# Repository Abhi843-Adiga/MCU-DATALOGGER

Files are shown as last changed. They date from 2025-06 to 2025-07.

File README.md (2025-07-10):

MCU Data Logger (2-Layer & 4-Layer PCB Design) :        
-> A compact, modular microcontroller-based data logger designed using KiCad.         
-> This project includes both 2-layer and 4-layer PCB implementations managed through Git branching and git attributes.

Design Disclaimer :
These PCB designs are provided for educational purposes only.

Passed Checks:
The designs have successfully passed basic ERC (Electrical Rules Check) and DRC (Design Rule Check) in the KICAD.

Untested Aspects:
These designs have not been validated for advanced electrical performance.
Critical aspects that have not been analyzed or tested include:
->Signal Integrity (SI):High-speed signals (like SPI) have not been analyzed for reflections or timing issues.
->Power Integrity (PI):The power delivery network has not been simulated for stability.
->EMI/EMC:The design has not been tested for electromagnetic interference or compatibility. 

It will likely not pass regulatory certifications without further revisions.

Do not use these designs for a production-ready or commercial product without performing a thorough analysis and validation for SI, PI, and EMC.

Contributing:
If you have experience in SI/PI analysis, EMC hardening, or would like to improve the design, please feel free to fork the repository and submit a pull request.

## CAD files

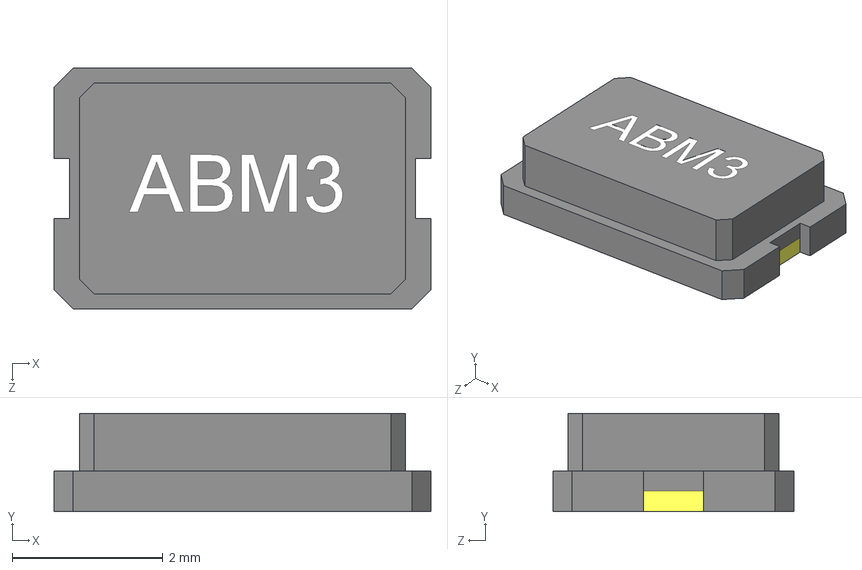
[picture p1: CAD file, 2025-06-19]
ABM3_16_000MHZ_B2_T/ABM3-16.000MHZ-B2-T.STEP
5.00 x 1.30 x 3.20 mm

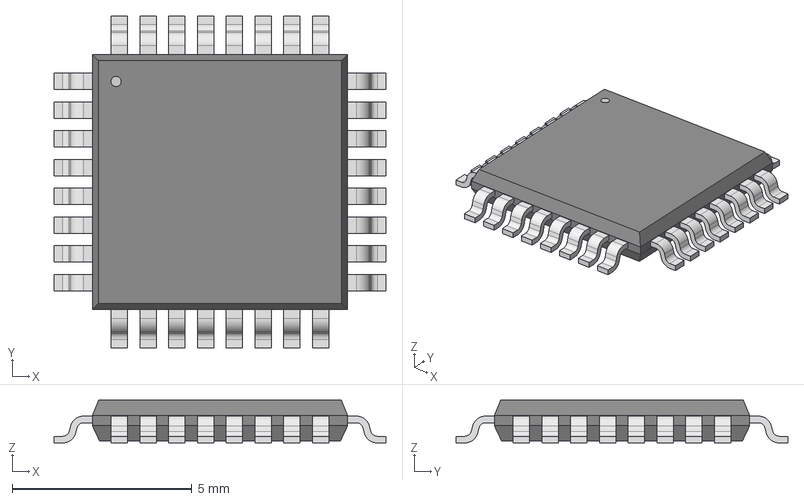
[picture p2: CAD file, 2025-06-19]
ATMEGA328P_AU (2)/TQFP32_32A_MCH.step
9.25 x 9.25 x 1.20 mm

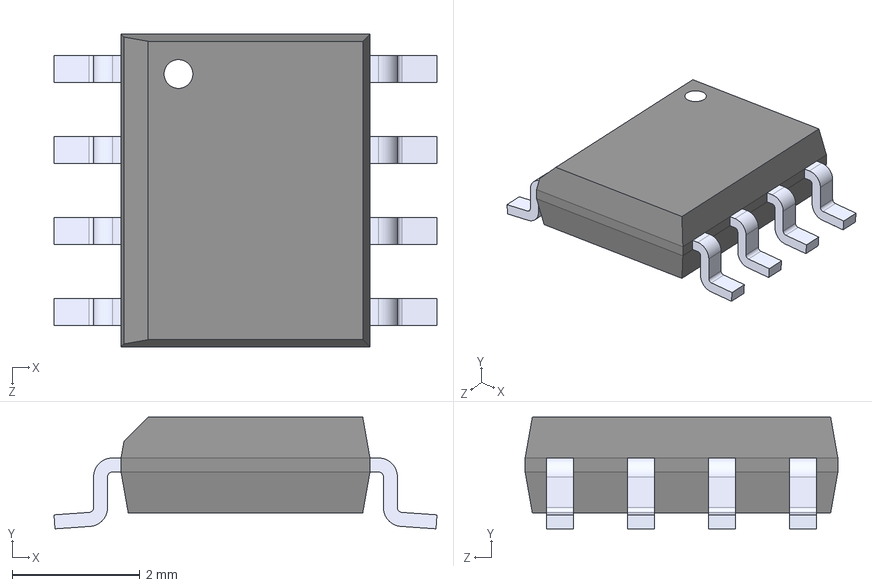
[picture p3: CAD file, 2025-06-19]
DS1337S (1)/DS1337S_.step
6.00 x 1.75 x 4.90 mm

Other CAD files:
ATMEGA328PB_AU/32A_MCH.step

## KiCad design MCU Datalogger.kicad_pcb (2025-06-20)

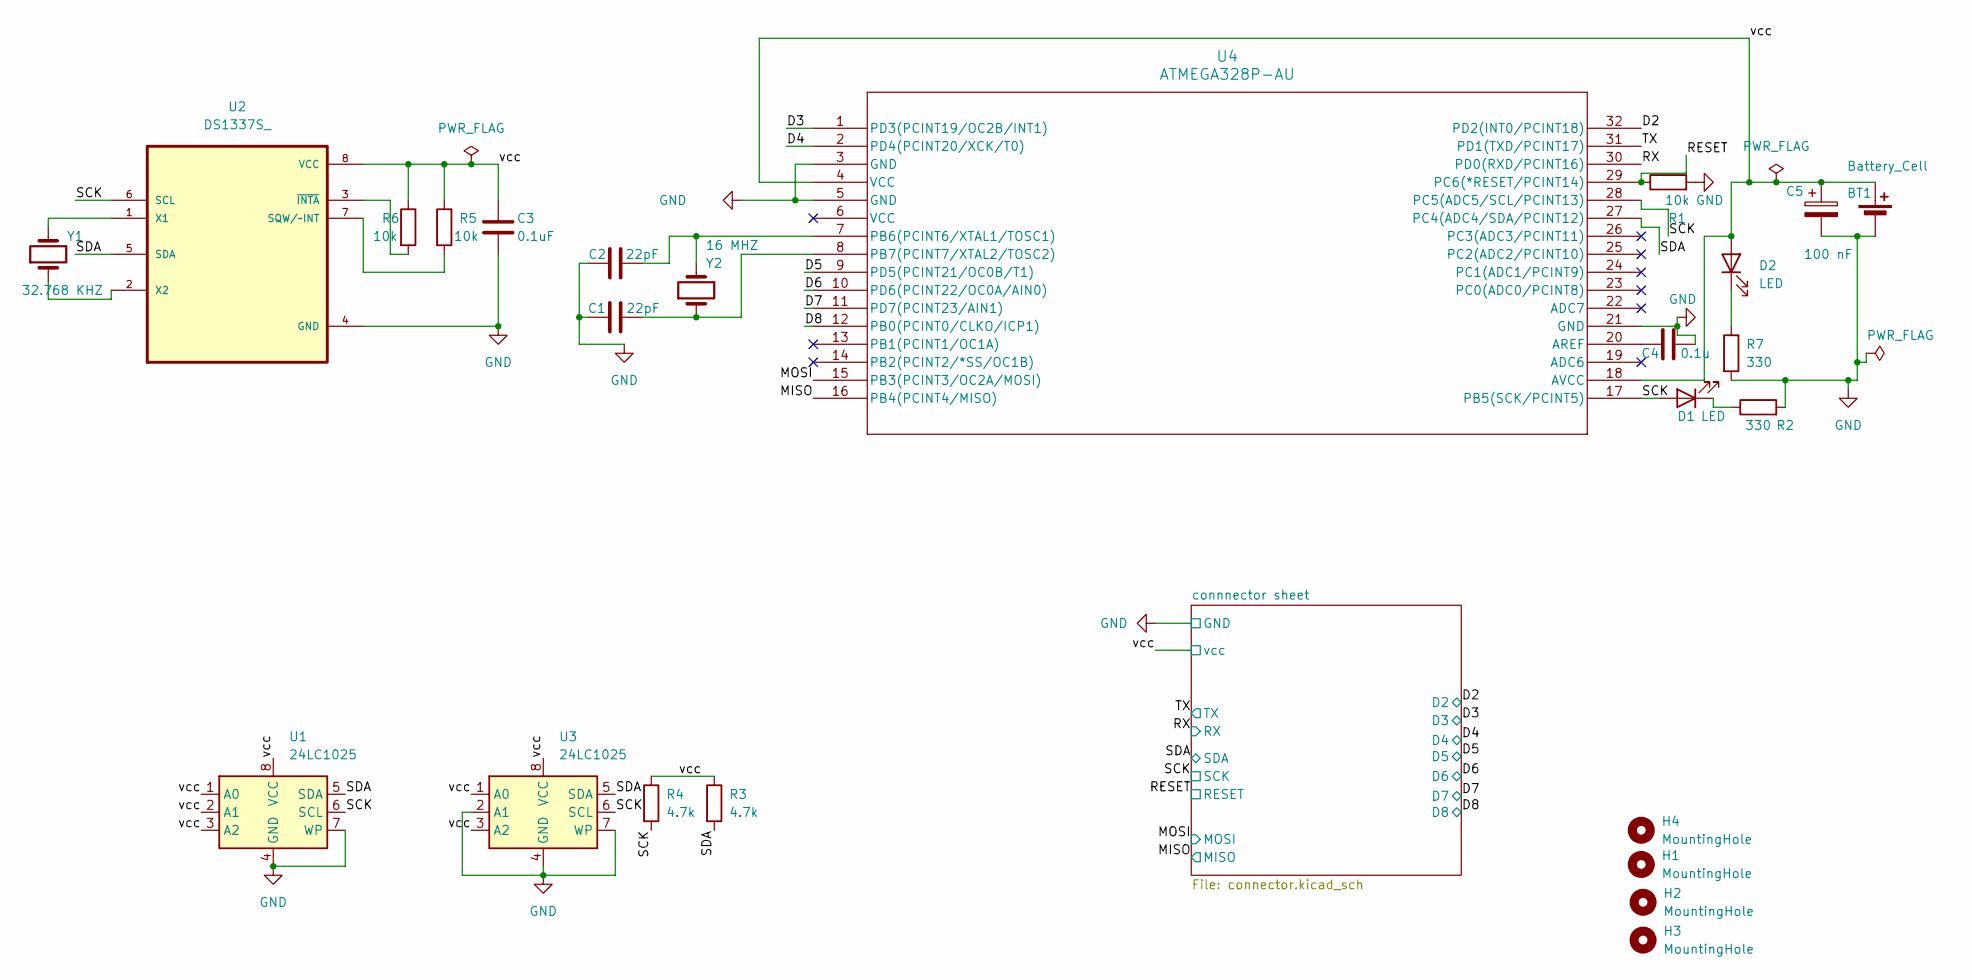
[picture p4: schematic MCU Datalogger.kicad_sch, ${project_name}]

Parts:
BT1: Battery_Cell; PinHeader_1x02_P2.54mm_Vertical
C1, C2: 22pF; C_0805_2012Metric
C3: 0.1uF; C_0805_2012Metric
C4: 0.1u; C_0805_2012Metric
C5: 100 nF; CP_Elec_3x5.3
D1, D2: LED; LED_0805_2012Metric
H1, H2, H3, H4: MountingHole; MountingHole_2.1mm
R1, R5, R6: 10k; R_0805_2012Metric
R2, R7: 330; R_0805_2012Metric
R3, R4: 4.7k; R_0805_2012Metric
U1, U3: 24LC1025; SOIC-8_3.9x4.9mm_P1.27mm
U2: DS1337S_; SOIC127P600X175-8N
U4: ATMEGA328P-AU; TQFP32_32A_MCH
Y1: 32.768 KHZ; Crystal_SMD_5032-2Pin_5.0x3.2mm_HandSoldering
Y2: 16 MHZ; Crystal_SMD_5032-2Pin_5.0x3.2mm_HandSoldering

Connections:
/D2: U4.32 (PD2(INT0/PCINT18)); also elsewhere on the board
/D3: U4.1 (PD3(PCINT19/OC2B/INT1)); also elsewhere on the board
/D4: U4.2 (PD4(PCINT20/XCK/T0)); also elsewhere on the board
/D5: U4.9 (PD5(PCINT21/OC0B/T1)); also elsewhere on the board
/D6: U4.10 (PD6(PCINT22/OC0A/AIN0)); also elsewhere on the board
/D7: U4.11 (PD7(PCINT23/AIN1)); also elsewhere on the board
/D8: U4.12 (PB0(PCINT0/CLKO/ICP1)); also elsewhere on the board
/MISO: U4.16 (PB4(PCINT4/MISO)); also elsewhere on the board
/MOSI: U4.15 (PB3(PCINT3/OC2A/MOSI)); also elsewhere on the board
/RESET: R1.1, U4.29 (PC6(*RESET/PCINT14)); also elsewhere on the board
/RX: U4.30 (PD0(RXD/PCINT16)); also elsewhere on the board
/SCK: D1.2 (A), R4.2, U1.6 (SCL), U2.6 (SCL), U3.6 (SCL), U4.17 (PB5(SCK/PCINT5)), U4.28 (PC5(ADC5/SCL/PCINT13)); also elsewhere on the board
/SDA: R3.2, U1.5 (SDA), U2.5 (SDA), U3.5 (SDA), U4.27 (PC4(ADC4/SDA/PCINT12)); also elsewhere on the board
/TX: U4.31 (PD1(TXD/PCINT17)); also elsewhere on the board
/vcc: BT1.1 (+), C3.1, C5.1, D2.2 (A), R3.1, R4.1, R5.1, R6.1, U1.1 (A0), U1.2 (A1), U1.3 (A2), U1.8 (VCC), U2.8 (VCC), U3.1 (A0), U3.3 (A2), U3.8 (VCC), U4.4 (VCC), U4.18 (AVCC); also elsewhere on the board
GND: BT1.2 (-), C1.1, C2.1, C3.2, C4.2, C5.2, R1.2, R2.2, R7.2, U1.4 (GND), U1.7 (WP), U2.4 (GND), U3.2 (A1), U3.4 (GND), U3.7 (WP), U4.3 (GND), U4.5 (GND), U4.21 (GND); also elsewhere on the board
unnamed: D1.1 (K), R2.1
unnamed: D2.1 (K), R7.1
unnamed: R5.2, U2.7 (SQW/~INT)
unnamed: U2.1 (X1), Y1.2
unnamed: U2.2 (X2), Y1.1
unnamed: R6.2, U2.3 (~INTA)
unnamed: C4.1, U4.20 (AREF)
unnamed: C2.2, U4.7 (PB6(PCINT6/XTAL1/TOSC1)), Y2.2
unnamed: C1.2, U4.8 (PB7(PCINT7/XTAL2/TOSC2)), Y2.1

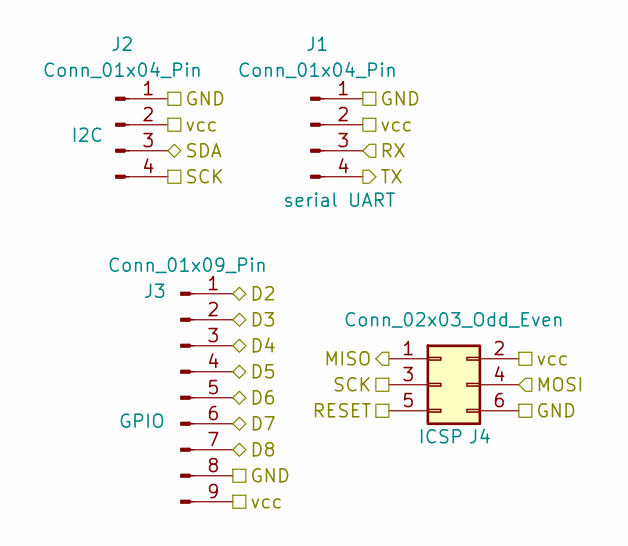
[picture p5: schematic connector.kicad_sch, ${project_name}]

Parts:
J1, J2: Conn_01x04_Pin; PinHeader_1x04_P2.54mm_Vertical
J3: Conn_01x09_Pin; PinHeader_1x09_P2.54mm_Vertical
J4: Conn_02x03_Odd_Even; PinHeader_2x03_P2.54mm_Vertical

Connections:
/D2: J3.1; also elsewhere on the board
/D3: J3.2; also elsewhere on the board
/D4: J3.3; also elsewhere on the board
/D5: J3.4; also elsewhere on the board
/D6: J3.5; also elsewhere on the board
/D7: J3.6; also elsewhere on the board
/D8: J3.7; also elsewhere on the board
/MISO: J4.1; also elsewhere on the board
/MOSI: J4.4; also elsewhere on the board
/RESET: J4.5; also elsewhere on the board
/RX: J1.3; also elsewhere on the board
/SCK: J2.4, J4.3; also elsewhere on the board
/SDA: J2.3; also elsewhere on the board
/TX: J1.4; also elsewhere on the board
/vcc: J1.2, J2.2, J3.9, J4.2; also elsewhere on the board
GND: J1.1, J2.1, J3.8, J4.6; also elsewhere on the board

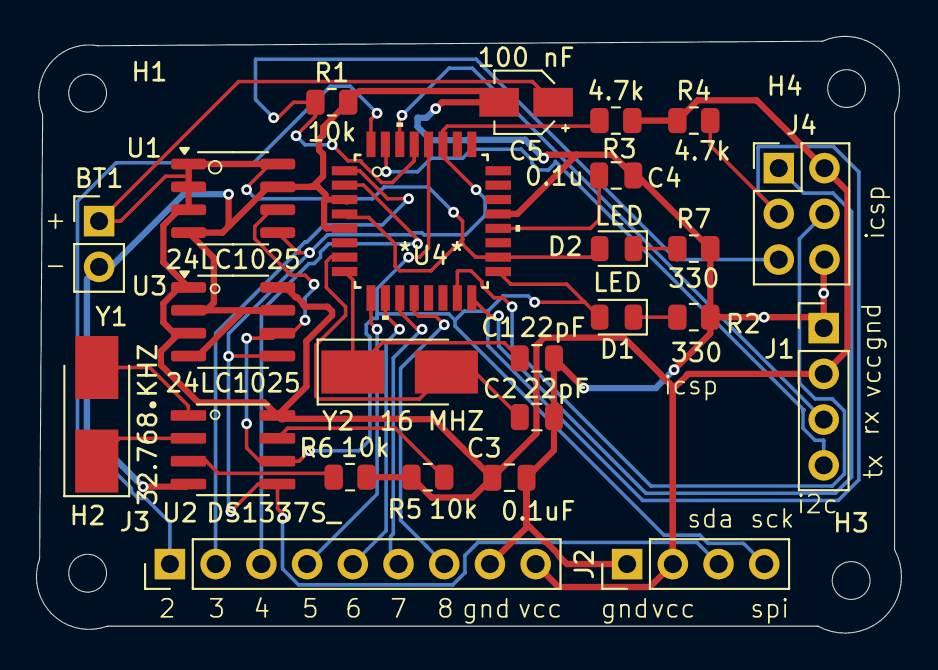
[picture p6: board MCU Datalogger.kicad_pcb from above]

Board: 2 copper layers, 48.1 x 33.1 mm, 29 parts (0 on the bottom side), 25 nets.

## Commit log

2025-06-18 Setup of EESchema
    [MCU Datalogger.kicad_sch]
2025-06-19 symbols initialized
    [32A_MCH.step, DS1337S_.step, MCU Datalogger.kicad_sch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]
2025-06-19 symbols updated
    [MCU Datalogger.kicad_sch, TQFP32_32A_MCH.step]
2025-06-19 symbols arranged
    [MCU Datalogger.kicad_sch, connector.kicad_sch]
2025-06-19 Added commponent values
    [MCU Datalogger.kicad_sch]
2025-06-19 Footprints Associated
    [ABM3-16.000MHZ-B2-T.STEP, MCU Datalogger.kicad_sch, connector.kicad_sch]
2025-06-19 Wiring of first sheet
    [MCU Datalogger.kicad_sch]
2025-06-19 COMPLETED THE WIRING AND RESOLVED ERC ERRORS SUCH AS POWER PIN ASSIGNMENT AND THE MCU UNIT SYMBOL TYPE(INPUT,OUTPUT,PASSIVE ETC
    [MCU Datalogger.kicad_sch, connector.kicad_sch]
2025-06-19 completion of schematic
    [MCU Datalogger.kicad_pcb]
2025-06-19 setup of pcbnew
    [MCU Datalogger.kicad_pcb]
2025-06-19 placed components
    [MCU Datalogger.kicad_pcb]
2025-06-19 Routing done and fixed the drc errors successfully
    [MCU Datalogger.kicad_pcb]
2025-06-20 copper fill and drc and refining the edge cuts completed
    [MCU Datalogger.kicad_pcb]
2025-06-20 arranged route tracks
    [MCU Datalogger.kicad_pcb]
2025-06-20 arranged route track and later the schematics there was small mistkae so arranged and routed successfully preparation for manufacturing
    [MCU Datalogger.kicad_pcb, MCU Datalogger.kicad_sch]
2025-06-20 completed full pcb 2 layer MCU datalogger
    [MCU Datalogger.kicad_pcb]
2025-06-23 fixed two defects in schematic
    [MCU Datalogger.kicad_sch, connector.kicad_sch]
